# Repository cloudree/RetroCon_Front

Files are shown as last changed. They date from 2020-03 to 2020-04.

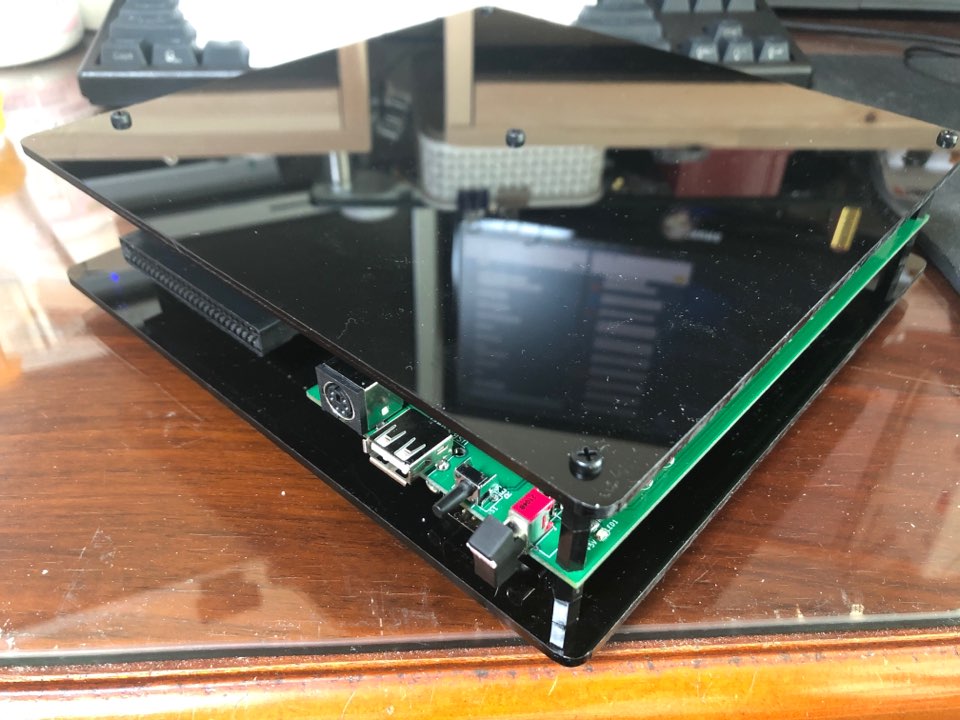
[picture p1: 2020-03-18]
Pictures/1_AcrylCased.JPG

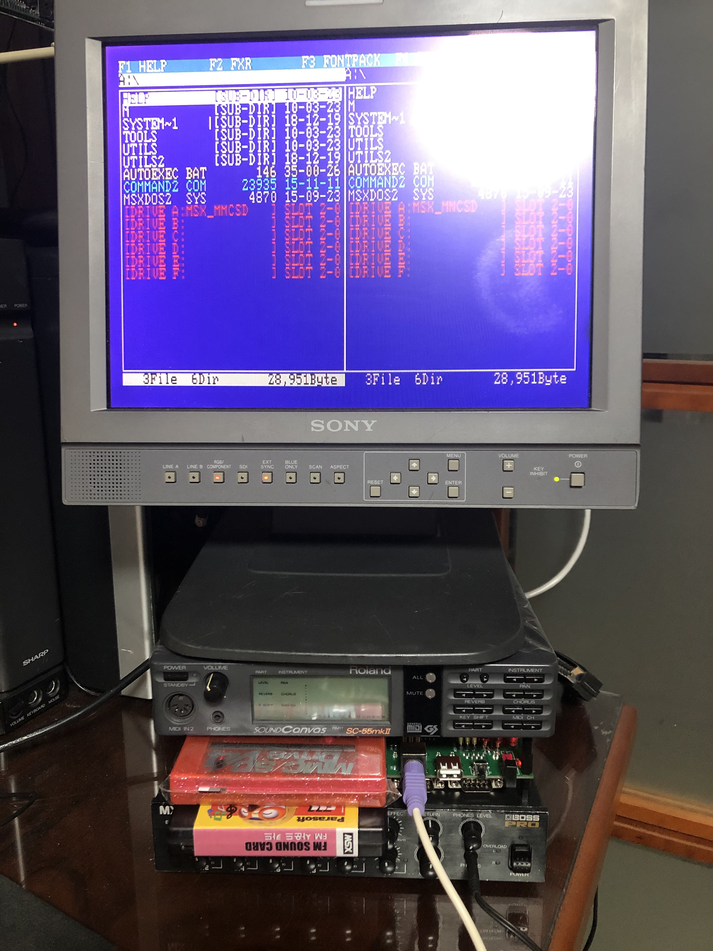
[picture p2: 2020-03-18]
Pictures/2_Between_MIDI_Devices.JPG

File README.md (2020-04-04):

# RetroCon_Front
Front Pack version of RetroCon (MSX2 compatible, VDP is V9958)
* Retrocon is MSX2+ compatible machine made by KevinCho ckevin@hanmail.net

/KiCad : schematics of Kicad

/CPLD : source for ALTERA EPM7128SLC84 CPLD, you must use Altera Quartus 13.0sp1 or below

/tinyFGPA : source for tinyFPGA board (PS/2 Keyboard interface)

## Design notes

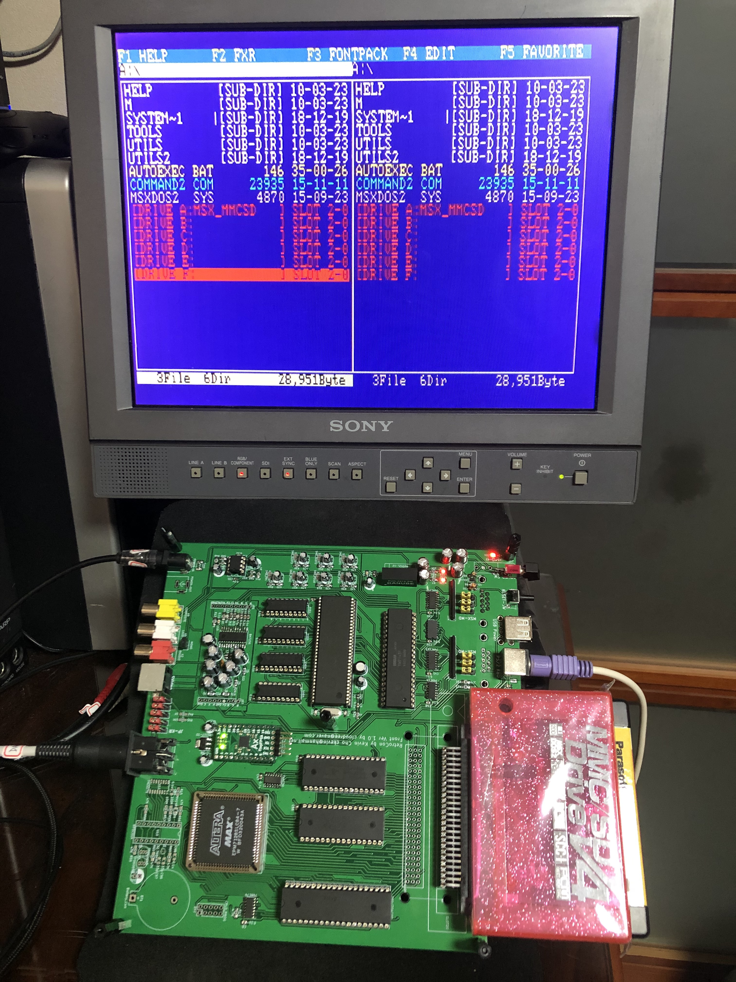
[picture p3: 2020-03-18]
Pictures/0_RetroCon.JPG

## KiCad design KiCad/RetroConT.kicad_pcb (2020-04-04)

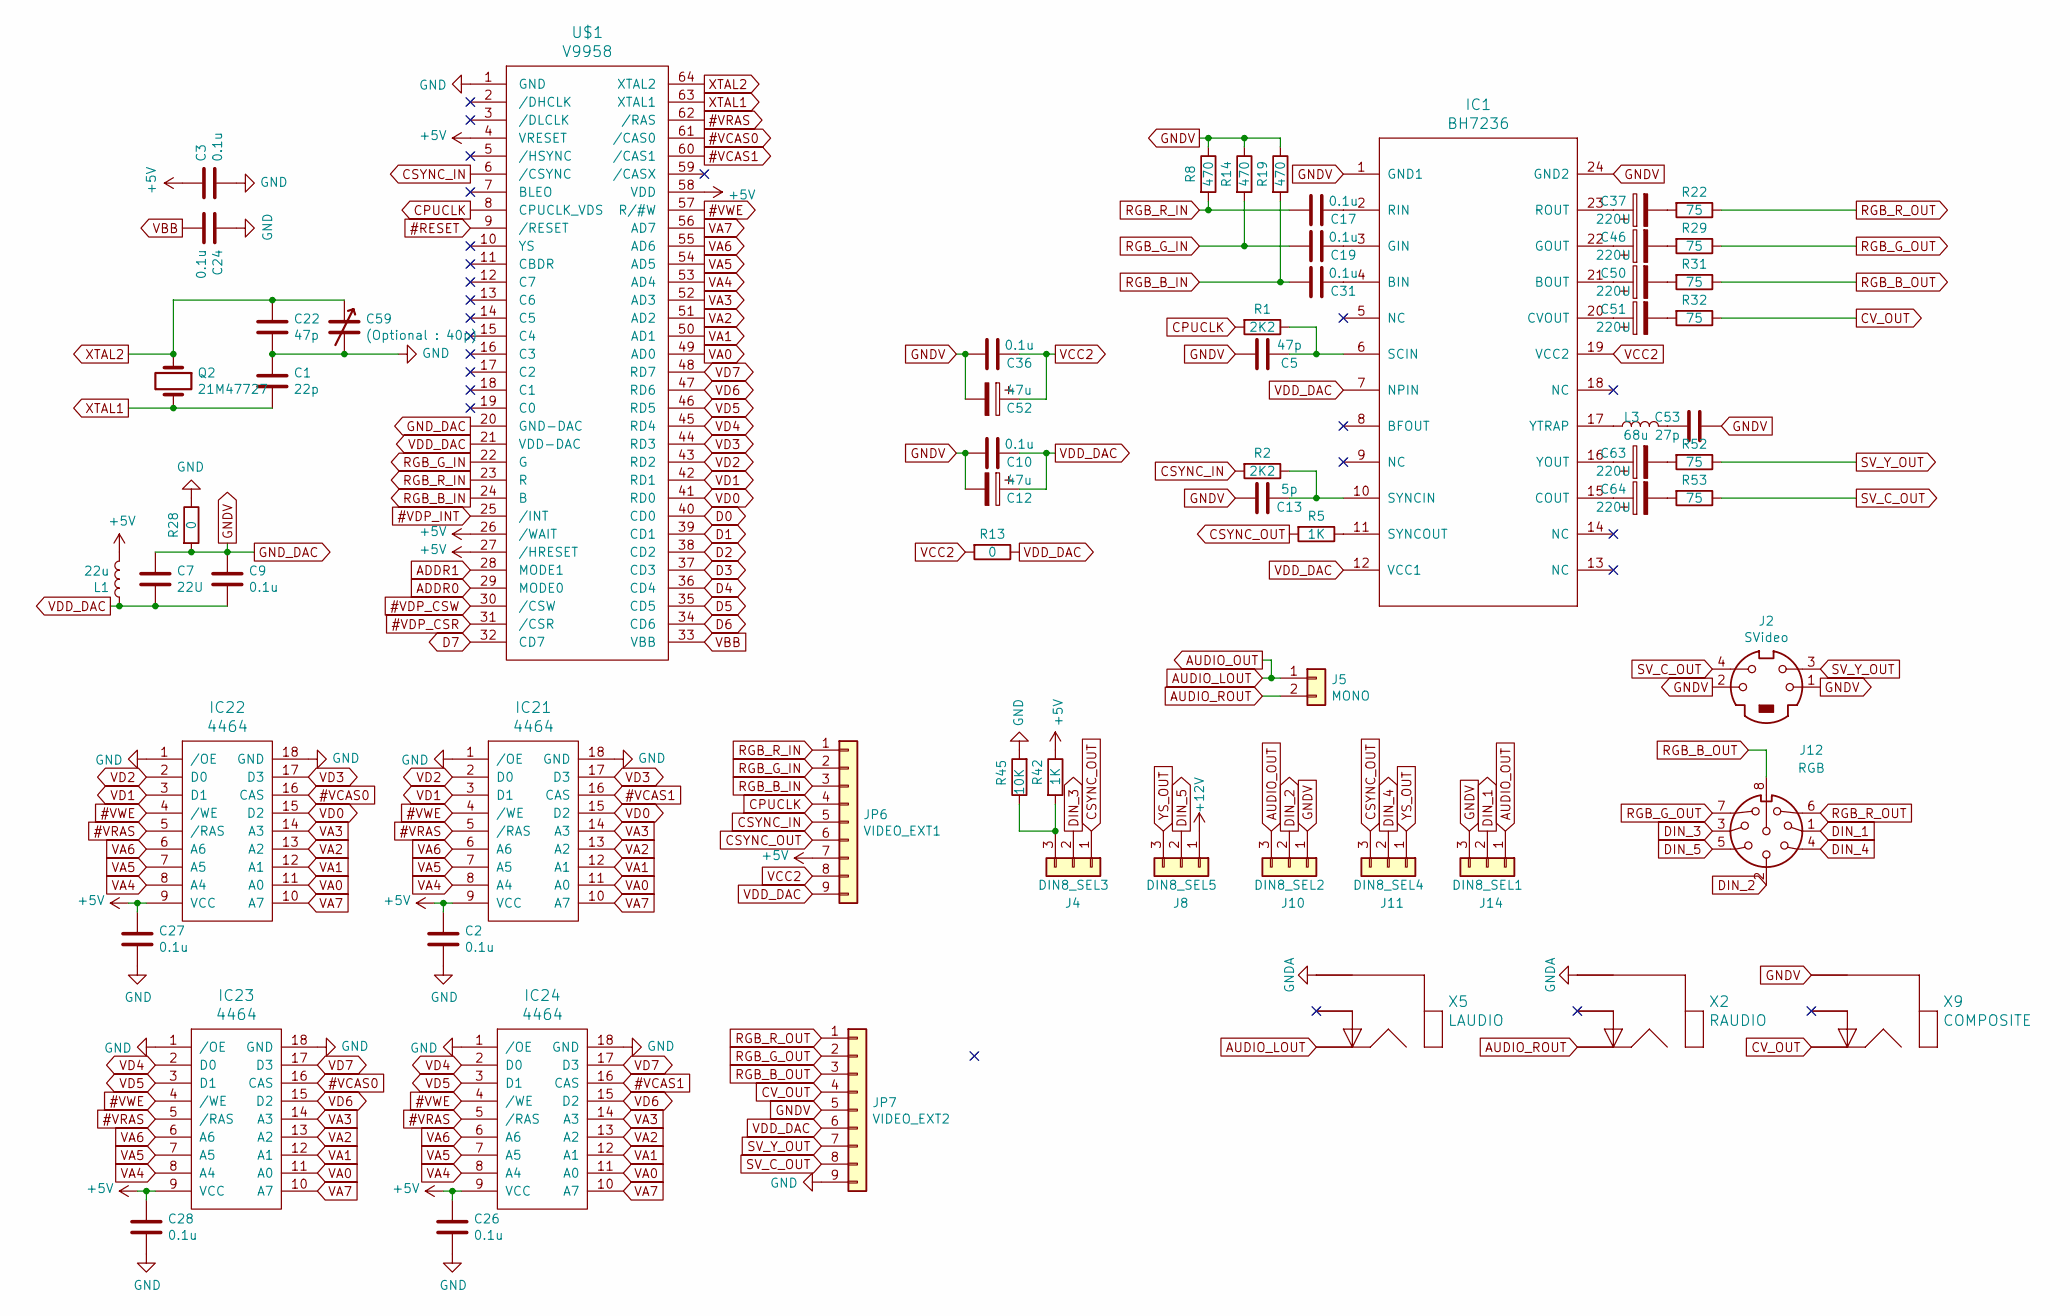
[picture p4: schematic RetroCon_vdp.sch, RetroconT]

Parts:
C1: 22p; C_0805_2012Metric_Pad1.15x1.40mm_HandSolder
C2, C3, C9, C10, C17, C19, C24, C26, C27, C28, C31, C36: 0.1u; C_0805_2012Metric_Pad1.15x1.40mm_HandSolder
C5, C22: 47p; C_0805_2012Metric_Pad1.15x1.40mm_HandSolder
C7: 22U; CP_Radial_D6.3mm_P2.50mm
C12, C52: 47u; CP_Radial_D6.3mm_P2.50mm
C13: 5p; C_0805_2012Metric_Pad1.15x1.40mm_HandSolder
C37, C46, C50, C51, C63, C64: 220U; CP_Radial_D6.3mm_P2.50mm
C53: 27p; C_0805_2012Metric_Pad1.15x1.40mm_HandSolder
C59: (Optional : 40p); C_Rect_L7.0mm_W6.5mm_P5.00mm
IC1: BH7236; SOP-24_7.5x15.4mm_P1.27mm
IC21, IC22, IC23, IC24: 4464; DIP-18_W7.62mm_Socket
J2: SVideo; Mini_din4
J4: DIN8_SEL3; PinHeader_1x03_P2.54mm_Vertical
J5: MONO; PinSocket_2x01_P2.54mm_Vertical
J8: DIN8_SEL5; PinHeader_1x03_P2.54mm_Vertical
J10: DIN8_SEL2; PinHeader_1x03_P2.54mm_Vertical
J11: DIN8_SEL4; PinHeader_1x03_P2.54mm_Vertical
J12: RGB; DIN-804_8P
J14: DIN8_SEL1; PinHeader_1x03_P2.54mm_Vertical
JP6: VIDEO_EXT1; PinHeader_1x09_P2.54mm_Vertical
JP7: VIDEO_EXT2; PinHeader_1x09_P2.54mm_Vertical
L1: 22u; L_0805_2012Metric_Pad1.15x1.40mm_HandSolder
L3: 68u; L_0805_2012Metric_Pad1.15x1.40mm_HandSolder
Q2: 21M47727; Crystal_HC49-U_Vertical
R1, R2: 2K2; R_0805_HandSoldering
R5, R42: 1K; R_0805_HandSoldering
R8, R14, R19: 470; R_0805_HandSoldering
R13, R28: 0; R_0805_HandSoldering
R22, R29, R31, R32, R52, R53: 75; R_0805_HandSoldering
R45: 10K; R_0805_HandSoldering
U$1: V9958; SDIP-64
X2: RAUDIO; RCA_102
X5: LAUDIO; RCA_102
X9: COMPOSITE; RCA_102

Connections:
#ExRESET: U$1.9 (/RESET); also elsewhere on the board
#VCAS0: IC22.16 (CAS), IC23.16 (CAS), U$1.61 (/CAS0)
#VCAS1: IC21.16 (CAS), IC24.16 (CAS), U$1.60 (/CAS1)
#VDP_CSR: U$1.31 (/CSR); also elsewhere on the board
#VDP_CSW: U$1.30 (/CSW); also elsewhere on the board
#VDP_INT: U$1.25 (/INT); also elsewhere on the board
#VRAS: IC21.5 (/RAS), IC22.5 (/RAS), IC23.5 (/RAS), IC24.5 (/RAS), U$1.62 (/RAS)
#VWE: IC21.4 (/WE), IC22.4 (/WE), IC23.4 (/WE), IC24.4 (/WE), U$1.57 (R/#W)
+5V: C2.1, C3.1, C26.1, C27.1, C28.1, IC21.9 (VCC), IC22.9 (VCC), IC23.9 (VCC), IC24.9 (VCC), JP6.7, L1.2, R42.1, U$1.4 (VRESET), U$1.26 (/WAIT), U$1.27 (/HRESET), U$1.58 (VDD); also elsewhere on the board
+12V: J8.1; also elsewhere on the board
ADDR0: U$1.29 (MODE0); also elsewhere on the board
ADDR1: U$1.28 (MODE1); also elsewhere on the board
AUDIO_LOUT: J5.1, J10.3, J14.1, X5.2; also elsewhere on the board
AUDIO_ROUT: J5.2, X2.2; also elsewhere on the board
CPUCLK: JP6.4, R1.2, U$1.8 (CPUCLK_VDS); also elsewhere on the board
CSYNC_IN: JP6.5, R2.2, U$1.6 (/CSYNC)
CSYNC_OUT: J4.1, J11.3, JP6.6, R5.2
CV_OUT: JP7.4, R32.1, X9.2
D0: U$1.40 (CD0); also elsewhere on the board
D1: U$1.39 (CD1); also elsewhere on the board
D2: U$1.38 (CD2); also elsewhere on the board
D3: U$1.37 (CD3); also elsewhere on the board
D4: U$1.36 (CD4); also elsewhere on the board
D5: U$1.35 (CD5); also elsewhere on the board
D6: U$1.34 (CD6); also elsewhere on the board
D7: U$1.32 (CD7); also elsewhere on the board
DIN_1: J12.1, J14.2
DIN_2: J10.2, J12.2
DIN_3: J4.2, J12.3
DIN_4: J11.2, J12.4
DIN_5: J8.2, J12.5
GND: C1.1, C2.2, C3.2, C22.2, C24.1, C26.2, C27.2, C28.2, C59.2, IC21.1 (/OE), IC21.18 (GND), IC22.1 (/OE), IC22.18 (GND), IC23.1 (/OE), IC23.18 (GND), IC24.1 (/OE), IC24.18 (GND), JP7.9, R28.1, R45.2, U$1.1 (GND); also elsewhere on the board
GNDA: X2.1, X5.1; also elsewhere on the board
GNDV: C5.2, C7.2, C9.2, C10.2, C12.2, C13.2, C36.2, C52.2, C53.2, IC1.1 (GND1), IC1.24 (GND2), J2.1, J2.2, J10.1, J14.3, JP7.5, R8.1, R14.1, R19.1, R28.2, U$1.20 (GND-DAC), X9.1
unnamed: C5.1, IC1.6 (SCIN), R1.1
unnamed: C13.1, IC1.10 (SYNCIN), R2.1
unnamed: C17.1, IC1.2 (RIN)
unnamed: C19.1, IC1.3 (GIN)
unnamed: C31.1, IC1.4 (BIN)
unnamed: C37.1, IC1.23 (ROUT)
unnamed: C37.2, R22.2
unnamed: C46.1, IC1.22 (GOUT)
unnamed: C46.2, R29.2
unnamed: C50.1, IC1.21 (BOUT)
unnamed: C50.2, R31.2
unnamed: C51.1, IC1.20 (CVOUT)
unnamed: C51.2, R32.2
unnamed: C53.1, L3.2
unnamed: C63.1, IC1.16 (YOUT)
unnamed: C63.2, R52.2
unnamed: C64.1, IC1.15 (COUT)
unnamed: C64.2, R53.2
unnamed: IC1.11 (SYNCOUT), R5.1
unnamed: IC1.17 (YTRAP), L3.1
unnamed: J4.3, R42.2, R45.1
RGB_B_IN: C31.2, JP6.3, R19.2, U$1.24 (B)
RGB_B_OUT: J12.8, JP7.3, R31.1
RGB_G_IN: C19.2, JP6.2, R14.2, U$1.22 (G)
RGB_G_OUT: J12.7, JP7.2, R29.1
RGB_R_IN: C17.2, JP6.1, R8.2, U$1.23 (R)
RGB_R_OUT: J12.6, JP7.1, R22.1
SV_C_OUT: J2.4, JP7.8, R53.1
SV_Y_OUT: J2.3, JP7.7, R52.1
VA0: IC21.11 (A0), IC22.11 (A0), IC23.11 (A0), IC24.11 (A0), U$1.49 (AD0)
VA1: IC21.12 (A1), IC22.12 (A1), IC23.12 (A1), IC24.12 (A1), U$1.50 (AD1)
VA2: IC21.13 (A2), IC22.13 (A2), IC23.13 (A2), IC24.13 (A2), U$1.51 (AD2)
VA3: IC21.14 (A3), IC22.14 (A3), IC23.14 (A3), IC24.14 (A3), U$1.52 (AD3)
VA4: IC21.8 (A4), IC22.8 (A4), IC23.8 (A4), IC24.8 (A4), U$1.53 (AD4)
VA5: IC21.7 (A5), IC22.7 (A5), IC23.7 (A5), IC24.7 (A5), U$1.54 (AD5)
VA6: IC21.6 (A6), IC22.6 (A6), IC23.6 (A6), IC24.6 (A6), U$1.55 (AD6)
VA7: IC21.10 (A7), IC22.10 (A7), IC23.10 (A7), IC24.10 (A7), U$1.56 (AD7)
VBB: C24.2, U$1.33 (VBB)
VCC2: C36.1, C52.1, IC1.19 (VCC2), JP6.8, R13.2
VD0: IC21.15 (D2), IC22.15 (D2), U$1.41 (RD0)
VD1: IC21.3 (D1), IC22.3 (D1), U$1.42 (RD1)
VD2: IC21.2 (D0), IC22.2 (D0), U$1.43 (RD2)
VD3: IC21.17 (D3), IC22.17 (D3), U$1.44 (RD3)
VD4: IC23.2 (D0), IC24.2 (D0), U$1.45 (RD4)
VD5: IC23.3 (D1), IC24.3 (D1), U$1.46 (RD5)
VD6: IC23.15 (D2), IC24.15 (D2), U$1.47 (RD6)
VD7: IC23.17 (D3), IC24.17 (D3), U$1.48 (RD7)
VDD_DAC: C7.1, C9.1, C10.1, C12.1, IC1.7 (NPIN), IC1.12 (VCC1), JP6.9, JP7.6, L1.1, R13.1, U$1.21 (VDD-DAC)
XTAL1: C1.2, Q2.2, U$1.63 (XTAL1)
XTAL2: C22.1, C59.1, Q2.1, U$1.64 (XTAL2)
YS_OUT: J8.3, J11.1

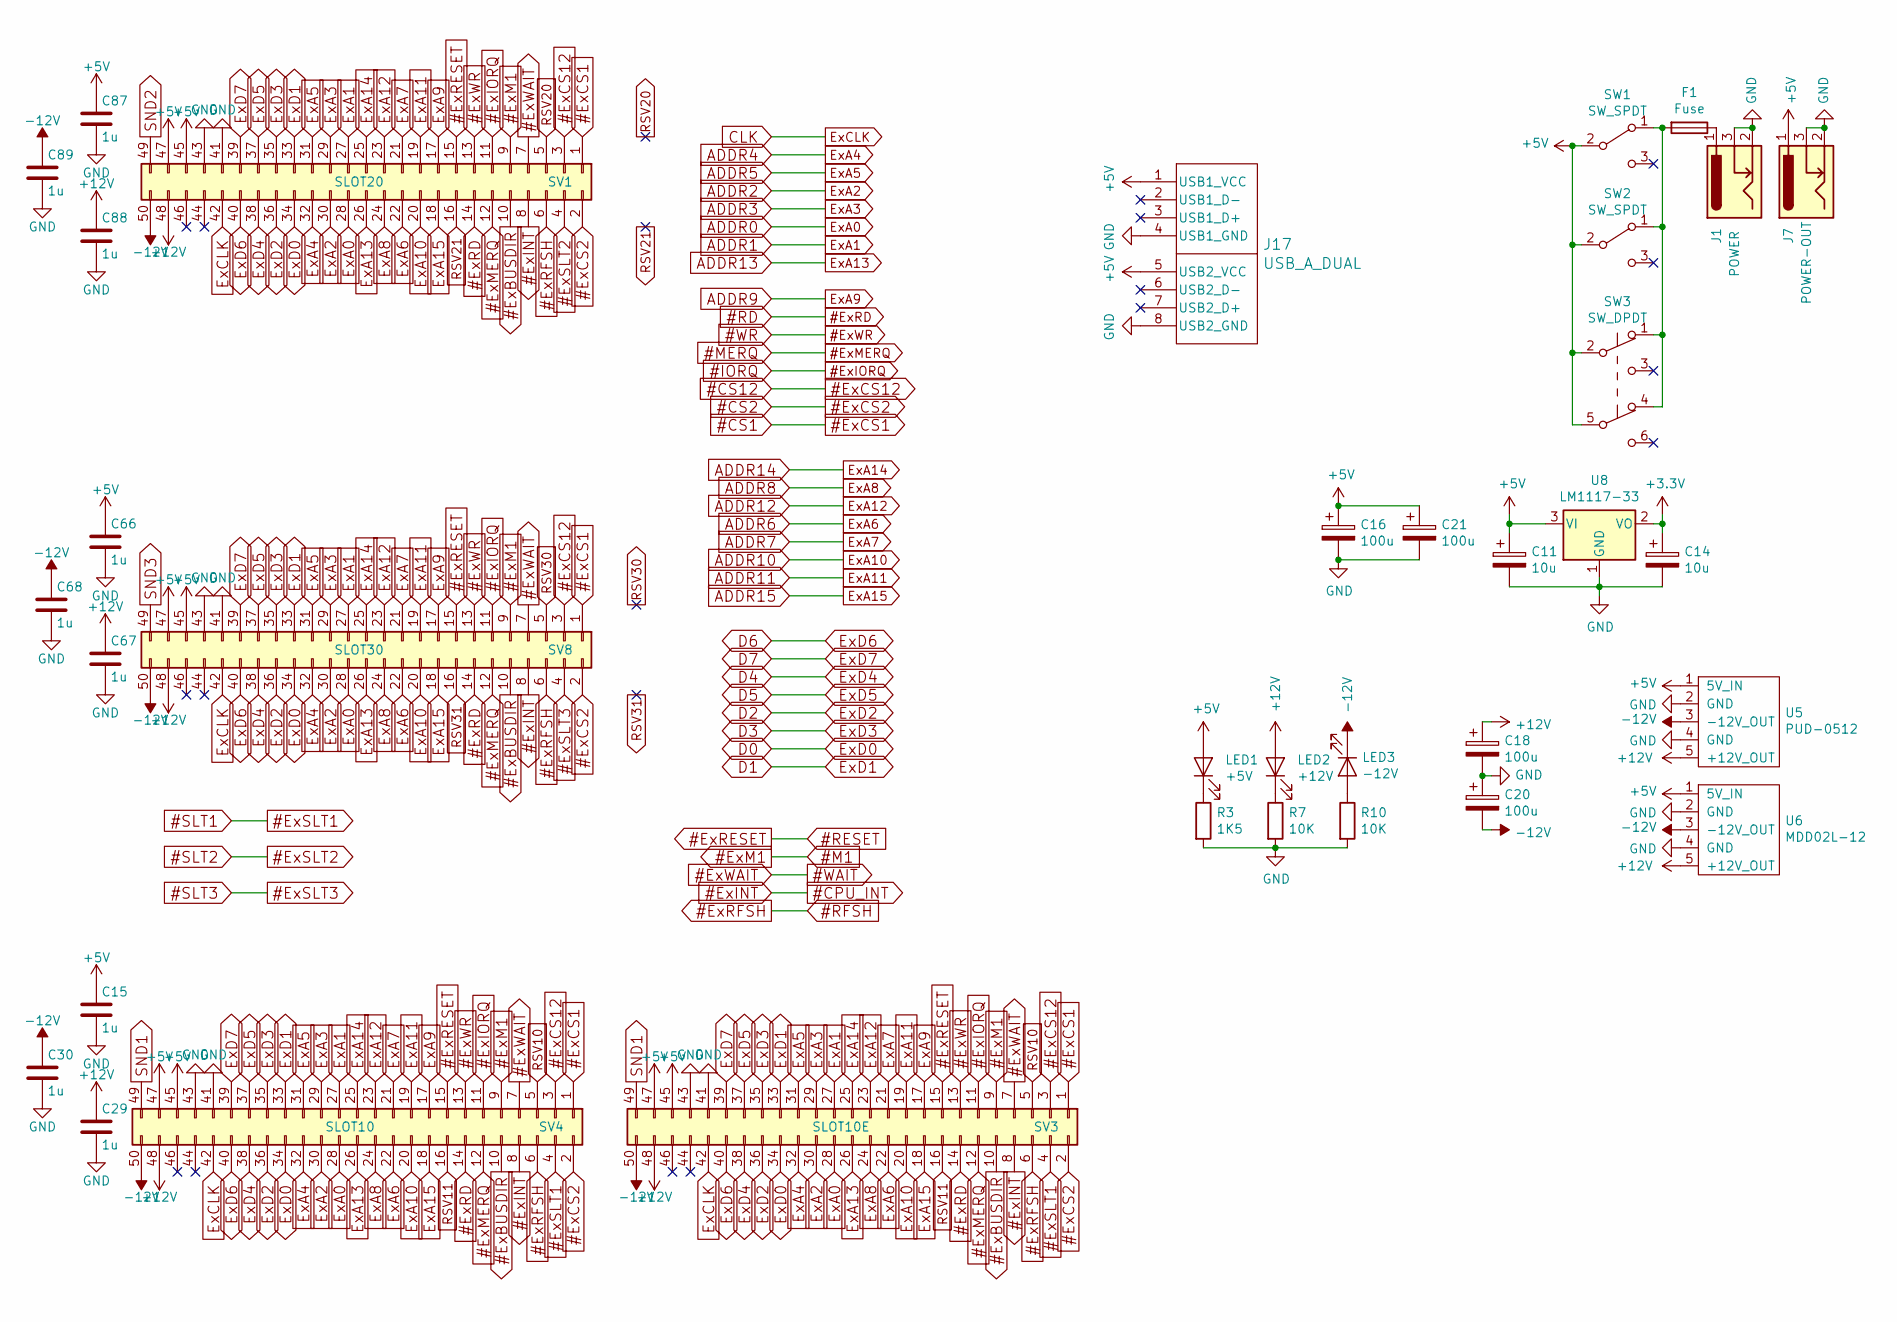
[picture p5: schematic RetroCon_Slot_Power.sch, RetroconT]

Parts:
C11, C14: 10u; CP_Radial_D6.3mm_P2.50mm
C15, C29, C30, C66, C67, C68, C87, C88, C89: 1u; C_0805_2012Metric_Pad1.15x1.40mm_HandSolder
C16, C18, C20, C21: 100u; CP_Radial_D6.3mm_P2.50mm
F1: Fuse; Fuse_1812_4532Metric_Pad1.30x3.40mm_HandSolder
J1: POWER; PO-PowerJack
J7: POWER-OUT; PO-PowerJack
J17: USB_A_DUAL
LED1: +5V; LED_0805_2012Metric
LED2: +12V; LED_0805_2012Metric
LED3: -12V; LED_0805_2012Metric
R3: 1K5; R_0805_HandSoldering
R7, R10: 10K; R_0805_HandSoldering
SV1: SLOT20; MSX_Edge_50_Slot
SV3: SLOT10E; MSX_Edge_50_Slot_Conencter
SV4: SLOT10; MSX_Edge_50_Slot
SV8: SLOT30; MSX_Edge_50_Slot_Universal
SW1: SW_SPDT; Switch-Toggle-Mini
SW2: SW_SPDT; MTS-102_Vertical_PCB
SW3: SW_DPDT; SW_DPDT_PS-22E05
U5: PUD-0512
U6: MDD02L-12
U8: LM1117-33; SOT-223-3_TabPin2

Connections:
#CPU_INT: SV1.8, SV3.8, SV4.8, SV8.8; also elsewhere on the board
#CS1: SV1.1, SV3.1, SV4.1, SV8.1; also elsewhere on the board
#CS2: SV1.2, SV3.2, SV4.2, SV8.2; also elsewhere on the board
#CS12: SV1.3, SV3.3, SV4.3, SV8.3; also elsewhere on the board
#ExBUSDIR: SV1.10, SV3.10, SV4.10, SV8.10
#ExIORQ: SV1.11, SV3.11, SV4.11, SV8.11; also elsewhere on the board
#ExM1: SV1.9, SV3.9, SV4.9, SV8.9; also elsewhere on the board
#ExMERQ: SV1.12, SV3.12, SV4.12, SV8.12; also elsewhere on the board
#ExRD: SV1.14, SV3.14, SV4.14, SV8.14; also elsewhere on the board
#ExRESET: SV1.15, SV3.15, SV4.15, SV8.15; also elsewhere on the board
#ExRFSH: SV1.6, SV3.6, SV4.6, SV8.6; also elsewhere on the board
#ExSLT1: SV3.4, SV4.4; also elsewhere on the board
#ExSLT2: SV1.4; also elsewhere on the board
#ExSLT3: SV8.4; also elsewhere on the board
#ExWAIT: SV1.7, SV3.7, SV4.7, SV8.7; also elsewhere on the board
#ExWR: SV1.13, SV3.13, SV4.13, SV8.13; also elsewhere on the board
+3V3: C14.1, U8.2 (VO); also elsewhere on the board
+5V: C11.1, C15.1, C16.1, C21.1, C66.1, C87.1, J7.1, J17.1 (USB1_VCC), J17.5 (USB2_VCC), LED1.2 (A), SV1.45, SV1.47, SV3.45, SV3.47, SV4.45, SV4.47, SV8.45, SV8.47, SW1.2 (B), SW2.2 (B), SW3.2 (B), SW3.5 (B), U5.1 (5V_IN), U6.1 (5V_IN), U8.3 (VI); also elsewhere on the board
+12V: C18.1, C29.1, C67.1, C88.1, LED2.2 (A), SV1.48, SV3.48, SV4.48, SV8.48, U5.5 (+12V_OUT), U6.5 (+12V_OUT); also elsewhere on the board
-12V: C20.2, C30.1, C68.1, C89.1, LED3.1 (K), SV1.50, SV3.50, SV4.50, SV8.50, U5.3 (-12V_OUT), U6.3 (-12V_OUT); also elsewhere on the board
ADDR0: SV1.28, SV3.28, SV4.28, SV8.28; also elsewhere on the board
ADDR1: SV1.27, SV3.27, SV4.27, SV8.27; also elsewhere on the board
ADDR2: SV1.30, SV3.30, SV4.30, SV8.30; also elsewhere on the board
ADDR3: SV1.29, SV3.29, SV4.29, SV8.29; also elsewhere on the board
ADDR4: SV1.32, SV3.32, SV4.32, SV8.32; also elsewhere on the board
ADDR5: SV1.31, SV3.31, SV4.31, SV8.31; also elsewhere on the board
ADDR6: SV1.22, SV3.22, SV4.22, SV8.22; also elsewhere on the board
ADDR7: SV1.21, SV3.21, SV4.21, SV8.21; also elsewhere on the board
ADDR8: SV1.24, SV3.24, SV4.24, SV8.24; also elsewhere on the board
ADDR9: SV1.17, SV3.17, SV4.17, SV8.17; also elsewhere on the board
ADDR10: SV1.20, SV3.20, SV4.20, SV8.20; also elsewhere on the board
ADDR11: SV1.19, SV3.19, SV4.19, SV8.19; also elsewhere on the board
ADDR12: SV1.23, SV3.23, SV4.23, SV8.23; also elsewhere on the board
ADDR13: SV1.26, SV3.26, SV4.26, SV8.26; also elsewhere on the board
ADDR14: SV1.25, SV3.25, SV4.25, SV8.25; also elsewhere on the board
ADDR15: SV1.18, SV3.18, SV4.18, SV8.18; also elsewhere on the board
CLK: SV1.42, SV3.42, SV4.42, SV8.42; also elsewhere on the board
D0: SV1.34, SV3.34, SV4.34, SV8.34; also elsewhere on the board
D1: SV1.33, SV3.33, SV4.33, SV8.33; also elsewhere on the board
D2: SV1.36, SV3.36, SV4.36, SV8.36; also elsewhere on the board
D3: SV1.35, SV3.35, SV4.35, SV8.35; also elsewhere on the board
D4: SV1.38, SV3.38, SV4.38, SV8.38; also elsewhere on the board
D5: SV1.37, SV3.37, SV4.37, SV8.37; also elsewhere on the board
D6: SV1.40, SV3.40, SV4.40, SV8.40; also elsewhere on the board
D7: SV1.39, SV3.39, SV4.39, SV8.39; also elsewhere on the board
GND: C11.2, C14.2, C15.2, C16.2, C18.2, C20.1, C21.2, C29.2, C30.2, C66.2, C67.2, C68.2, C87.2, C88.2, C89.2, J1.2, J1.3, J7.2, J7.3, J17.4 (USB1_GND), J17.8 (USB2_GND), R3.2, R7.2, R10.2, SV1.41, SV1.43, SV3.41, SV3.43, SV4.41, SV4.43, SV8.41, SV8.43, U5.2 (GND), U5.4 (GND), U6.2 (GND), U6.4 (GND), U8.1 (GND); also elsewhere on the board
unnamed: F1.1, J1.1
unnamed: F1.2, SW1.1 (A), SW2.1 (A), SW3.1 (A), SW3.4 (A)
unnamed: LED1.1 (K), R3.1
unnamed: LED2.1 (K), R7.1
unnamed: LED3.2 (A), R10.1
RSV10: SV3.5, SV4.5
RSV11: SV3.16, SV4.16
RSV20: SV1.5
RSV21: SV1.16
RSV30: SV8.5
RSV31: SV8.16
SND1: SV3.49, SV4.49; also elsewhere on the board
SND2: SV1.49; also elsewhere on the board
SND3: SV8.49; also elsewhere on the board

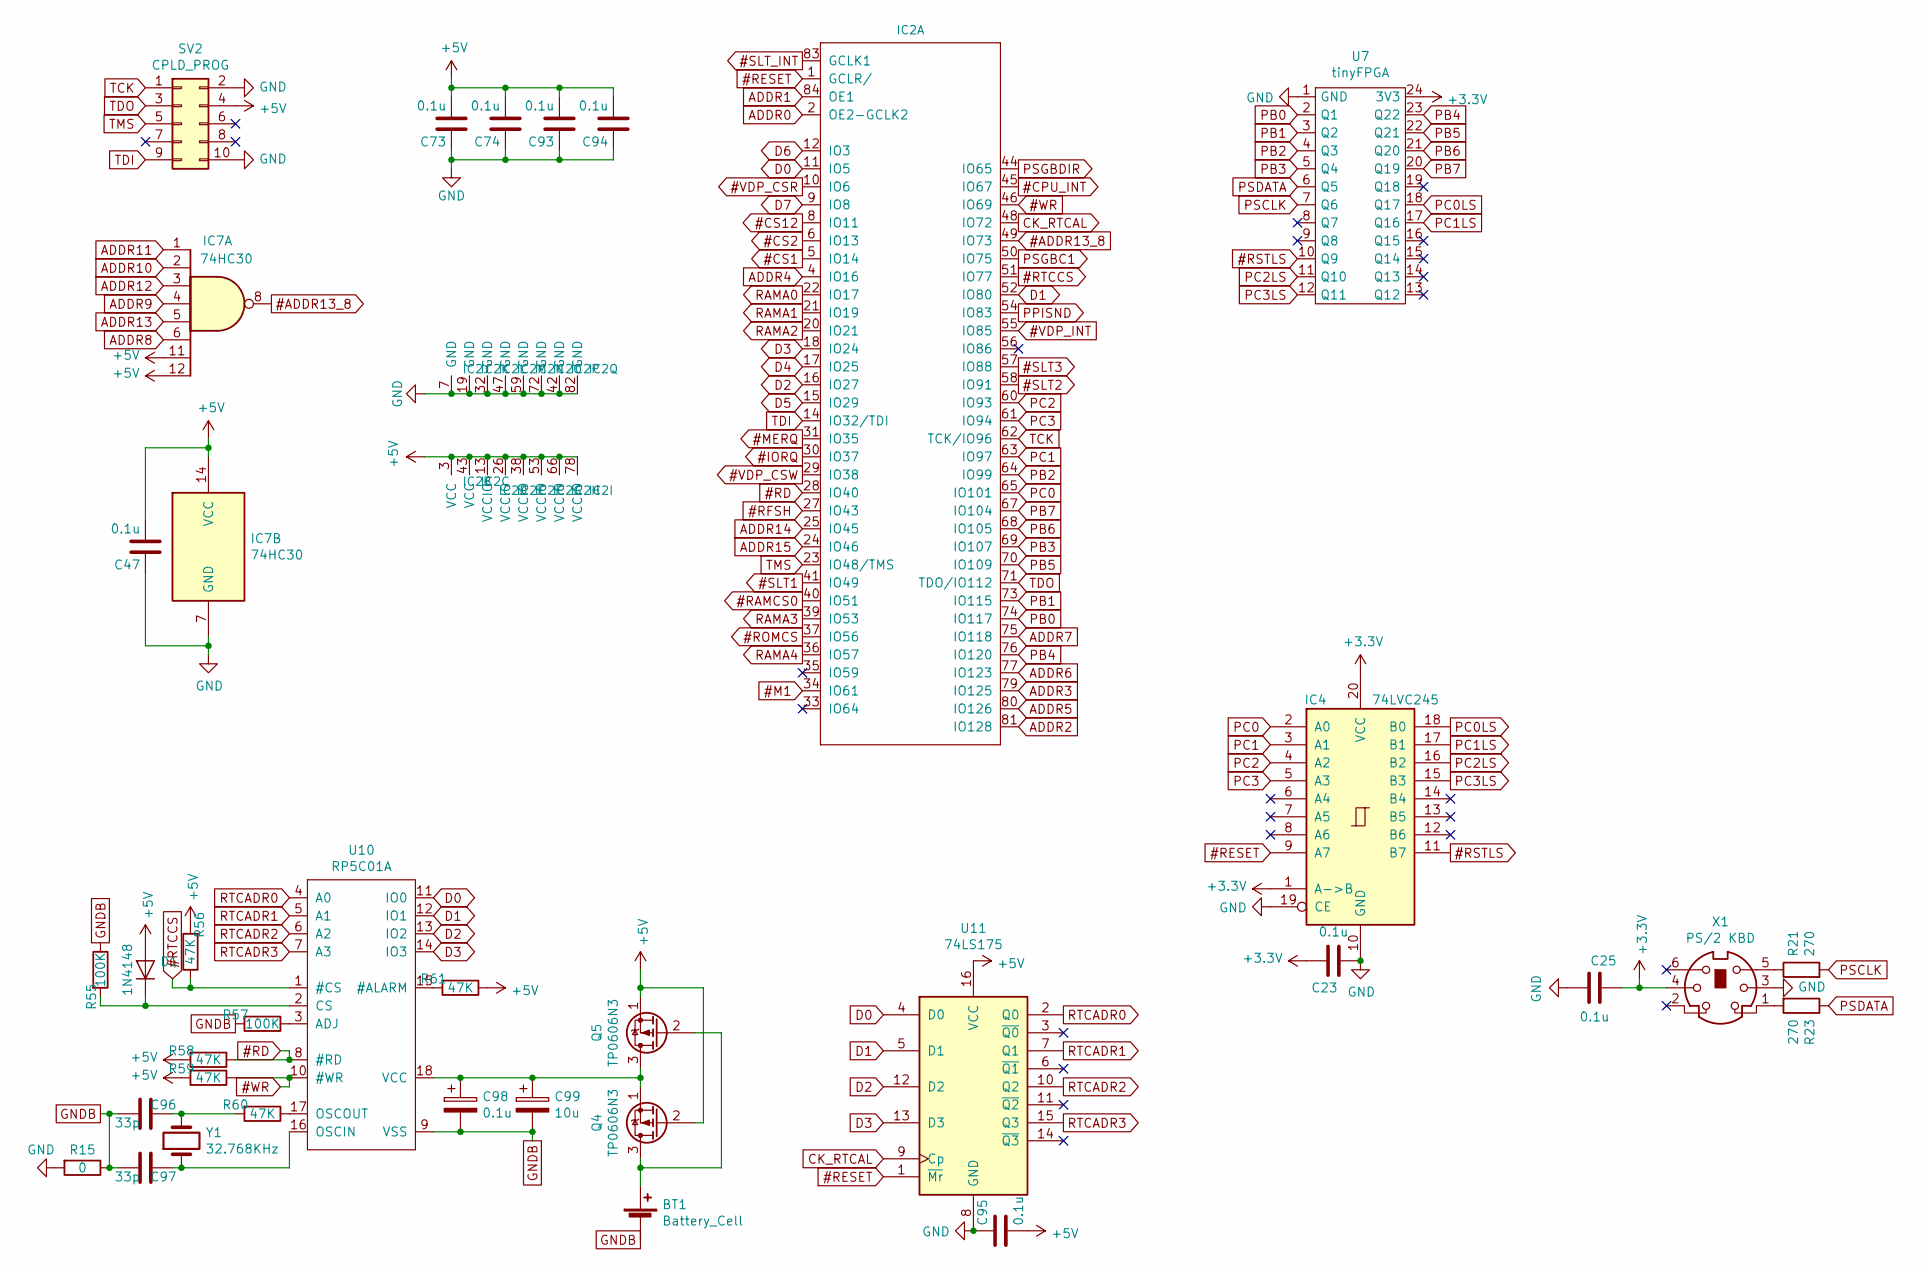
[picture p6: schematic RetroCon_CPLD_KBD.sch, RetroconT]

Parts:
BT1: Battery_Cell; BatteryHolder_Keystone_104_1x23mm
C23, C25, C47, C73, C74, C93, C94, C95, C98: 0.1u; C_0805_2012Metric_Pad1.15x1.40mm_HandSolder
C96, C97: 33p; C_0805_2012Metric_Pad1.15x1.40mm_HandSolder
C99: 10u; CP_Radial_D6.3mm_P2.50mm
D1: 1N4148; D_0805_2012Metric_Pad1.15x1.40mm_HandSolder
IC2: EPM7128-J84SOC-RetroCon-eagle-import; PLCC-84_THT-Socket
IC4: 74LVC245; DIP-20_W7.62mm_Socket
IC7: 74HC30; SOIC-14_3.9x8.7mm_P1.27mm
Q4, Q5: TP0606N3; TO-92_Inline
R15: 0; R_0805_HandSoldering
R21, R23: 270; R_0805_HandSoldering
R55, R57: 100K; R_0805_HandSoldering
R56, R58, R59, R60, R61: 47K; R_0805_HandSoldering
SV2: CPLD_PROG; PinHeader_2x05_P2.54mm_Vertical
U7: tinyFPGA; DIP-24_W15.24mm
U10: RP5C01A; DIP-18_W7.62mm_Socket
U11: 74LS175; SOIC-16_3.9x9.9mm_P1.27mm
X1: PS/2 KBD; Mini_din6
Y1: 32.768KHz; Crystal_DS26_D2.0mm_L6.0mm_Vertical

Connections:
#ADDR13_8: IC2.49 (IO73), IC7.8
#CPU_INT: IC2.45 (IO67); also elsewhere on the board
#CS1: IC2.5 (IO14); also elsewhere on the board
#CS2: IC2.6 (IO13); also elsewhere on the board
#CS12: IC2.8 (IO11); also elsewhere on the board
#ExIORQ: IC2.30 (IO37); also elsewhere on the board
#ExM1: IC2.34 (IO61); also elsewhere on the board
#ExMERQ: IC2.31 (IO35); also elsewhere on the board
#ExRD: IC2.28 (IO40), R58.1, U10.8 (#RD); also elsewhere on the board
#ExRESET: IC2.1 (GCLR/), IC4.9 (A7), U11.1 (~Mr); also elsewhere on the board
#ExRFSH: IC2.27 (IO43); also elsewhere on the board
#ExSLT1: IC2.41 (IO49); also elsewhere on the board
#ExSLT2: IC2.58 (IO91); also elsewhere on the board
#ExSLT3: IC2.57 (IO88); also elsewhere on the board
#ExWR: IC2.46 (IO69), R59.1, U10.10 (#WR); also elsewhere on the board
#RAMCS0: IC2.40 (IO51); also elsewhere on the board
#ROMCS: IC2.37 (IO56); also elsewhere on the board
#RSTLS: IC4.11 (B7), U7.10 (Q9)
#RTCCS: IC2.51 (IO77), R56.1, U10.1 (#CS)
#SLT_INT: IC2.83 (GCLK1); also elsewhere on the board
#VDP_CSR: IC2.10 (IO6); also elsewhere on the board
#VDP_CSW: IC2.29 (IO38); also elsewhere on the board
#VDP_INT: IC2.55 (IO85); also elsewhere on the board
+3V3: C23.2, C25.2, IC4.1 (A->B), IC4.20 (VCC), U7.24 (3V3), X1.4; also elsewhere on the board
+5V: C47.2, C73.2, C74.2, C93.2, C94.2, C95.2, D1.2 (A), IC2.3 (VCC), IC2.13 (VCCIO), IC2.26 (VCCIO), IC2.38 (VCCIO), IC2.43 (VCC), IC2.53 (VCCIO), IC2.66 (VCCIO), IC2.78 (VCCIO), IC7.11, IC7.12, IC7.14 (VCC), Q4.2 (G), Q5.1 (S), R56.2, R58.2, R59.2, R61.1, SV2.4, U11.16 (VCC); also elsewhere on the board
ADDR0: IC2.2 (OE2-GCLK2); also elsewhere on the board
ADDR1: IC2.84 (OE1); also elsewhere on the board
ADDR2: IC2.81 (IO128); also elsewhere on the board
ADDR3: IC2.79 (IO125); also elsewhere on the board
ADDR4: IC2.4 (IO16); also elsewhere on the board
ADDR5: IC2.80 (IO126); also elsewhere on the board
ADDR6: IC2.77 (IO123); also elsewhere on the board
ADDR7: IC2.75 (IO118); also elsewhere on the board
ADDR8: IC7.6; also elsewhere on the board
ADDR9: IC7.4; also elsewhere on the board
ADDR10: IC7.2; also elsewhere on the board
ADDR11: IC7.1; also elsewhere on the board
ADDR12: IC7.3; also elsewhere on the board
ADDR13: IC7.5; also elsewhere on the board
ADDR14: IC2.25 (IO45); also elsewhere on the board
ADDR15: IC2.24 (IO46); also elsewhere on the board
CK_RTCAL: IC2.48 (IO72), U11.9 (Cp)
D0: IC2.11 (IO5), U10.11 (IO0), U11.4 (D0); also elsewhere on the board
D1: IC2.52 (IO80), U10.12 (IO1), U11.5 (D1); also elsewhere on the board
D2: IC2.16 (IO27), U10.13 (IO2), U11.12 (D2); also elsewhere on the board
D3: IC2.18 (IO24), U10.14 (IO3), U11.13 (D3); also elsewhere on the board
D4: IC2.17 (IO25); also elsewhere on the board
D5: IC2.15 (IO29); also elsewhere on the board
D6: IC2.12 (IO3); also elsewhere on the board
D7: IC2.9 (IO8); also elsewhere on the board
GND: C23.1, C25.1, C47.1, C73.1, C74.1, C93.1, C94.1, C95.1, IC2.7 (GND), IC2.19 (GND), IC2.32 (GND), IC2.42 (GND), IC2.47 (GND), IC2.59 (GND), IC2.72 (GND), IC2.82 (GND), IC4.10 (GND), IC4.19 (CE), IC7.7 (GND), R15.2, SV2.2, SV2.10, U7.1 (GND), U11.8 (GND), X1.3; also elsewhere on the board
GNDB: BT1.2 (-), C96.1, C97.1, C98.2, C99.2, R15.1, R55.1, R57.2, U10.9 (VSS)
unnamed: BT1.1 (+), Q4.3 (D), Q5.2 (G)
unnamed: C96.2, R60.2, Y1.2
unnamed: C97.2, U10.16 (OSCIN), Y1.1
unnamed: C98.1, C99.1, Q4.1 (S), Q5.3 (D), U10.18 (VCC)
unnamed: D1.1 (K), R55.2, U10.2 (CS)
unnamed: R21.1, X1.5
unnamed: R23.2, X1.1
unnamed: R57.1, U10.3 (ADJ)
unnamed: R60.1, U10.17 (OSCOUT)
unnamed: R61.2, U10.15 (#ALARM)
PB0: IC2.74 (IO117), U7.2 (Q1)
PB1: IC2.73 (IO115), U7.3 (Q2)
PB2: IC2.64 (IO99), U7.4 (Q3)
PB3: IC2.69 (IO107), U7.5 (Q4)
PB4: IC2.76 (IO120), U7.23 (Q22)
PB5: IC2.70 (IO109), U7.22 (Q21)
PB6: IC2.68 (IO105), U7.21 (Q20)
PB7: IC2.67 (IO104), U7.20 (Q19)
PC0: IC2.65 (IO101), IC4.2 (A0)
PC0LS: IC4.18 (B0), U7.18 (Q17)
PC1: IC2.63 (IO97), IC4.3 (A1)
PC1LS: IC4.17 (B1), U7.17 (Q16)
PC2: IC2.60 (IO93), IC4.4 (A2)
PC2LS: IC4.16 (B2), U7.11 (Q10)
PC3: IC2.61 (IO94), IC4.5 (A3)
PC3LS: IC4.15 (B3), U7.12 (Q11)
PPISND: IC2.54 (IO83); also elsewhere on the board
PSCLK: R21.2, U7.7 (Q6)
PSDATA: R23.1, U7.6 (Q5)
PSGBC1: IC2.50 (IO75); also elsewhere on the board
PSGBDIR: IC2.44 (IO65); also elsewhere on the board
RAMA0: IC2.22 (IO17); also elsewhere on the board
RAMA1: IC2.21 (IO19); also elsewhere on the board
RAMA2: IC2.20 (IO21); also elsewhere on the board
RAMA3: IC2.39 (IO53); also elsewhere on the board
RAMA4: IC2.36 (IO57); also elsewhere on the board
RTCADR0: U10.4 (A0), U11.2 (Q0)
RTCADR1: U10.5 (A1), U11.7 (Q1)
RTCADR2: U10.6 (A2), U11.10 (Q2)
RTCADR3: U10.7 (A3), U11.15 (Q3)
TCK: IC2.62 (TCK/IO96), SV2.1
TDI: IC2.14 (IO32/TDI), SV2.9
TDO: IC2.71 (TDO/IO112), SV2.3
TMS: IC2.23 (IO48/TMS), SV2.5

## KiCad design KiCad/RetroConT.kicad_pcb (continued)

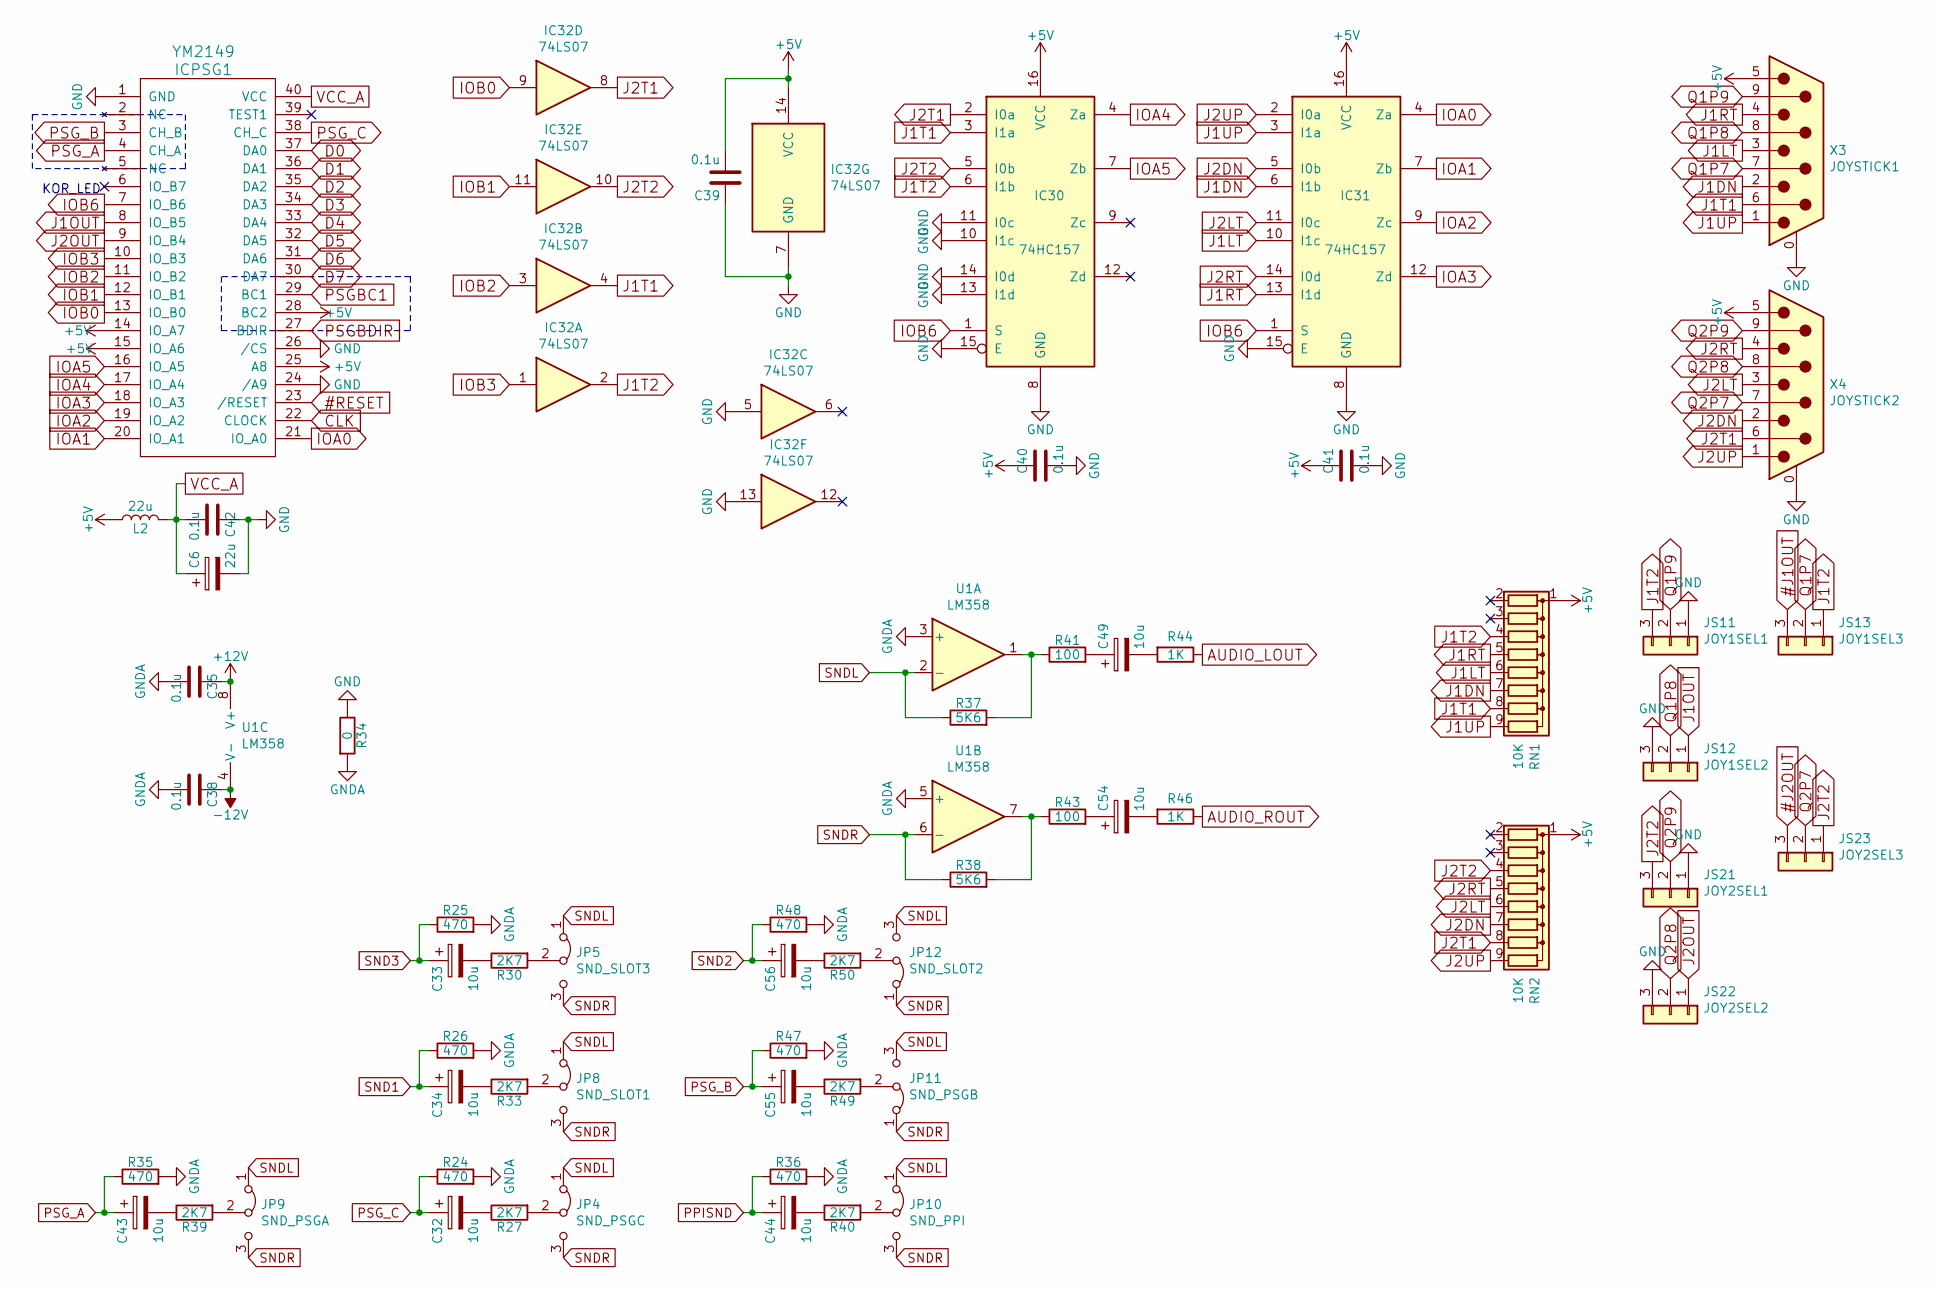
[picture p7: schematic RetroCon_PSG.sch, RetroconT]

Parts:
C6: 22u; CP_Radial_D6.3mm_P2.50mm
C32, C33, C34, C43, C44, C49, C54, C55, C56: 10u; CP_Radial_D6.3mm_P2.50mm
C35, C38, C39, C40, C41, C42: 0.1u; C_0805_2012Metric_Pad1.15x1.40mm_HandSolder
IC30, IC31: 74HC157; SOIC-16_3.9x9.9mm_P1.27mm
IC32: 74LS07; SOIC-14_3.9x8.7mm_P1.27mm
ICPSG1: YM2149; DIP-40_W15.24mm_Socket
JP4: SND_PSGC; SolderJumper-3_P1.3mm_Bridged12_RoundedPad1.0x1.5mm_NumberL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
JP5: SND_SLOT3; SolderJumper-3_P1.3mm_Bridged12_RoundedPad1.0x1.5mm_NumberL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
JP8: SND_SLOT1; SolderJumper-3_P1.3mm_Bridged12_RoundedPad1.0x1.5mm_NumberL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
JP9: SND_PSGA; SolderJumper-3_P1.3mm_Bridged12_RoundedPad1.0x1.5mm_NumberL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
JP10: SND_PPI; SolderJumper-3_P1.3mm_Bridged12_RoundedPad1.0x1.5mm_NumberL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
JP11: SND_PSGB; SolderJumper-3_P1.3mm_Bridged12_RoundedPad1.0x1.5mm_NumberL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
JP12: SND_SLOT2; SolderJumper-3_P1.3mm_Bridged12_RoundedPad1.0x1.5mm_NumberL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
JS11: JOY1SEL1; PinSocket_1x03_P2.54mm_Vertical
JS12: JOY1SEL2; PinSocket_1x03_P2.54mm_Vertical
JS13: JOY1SEL3; PinSocket_1x03_P2.54mm_Vertical
JS21: JOY2SEL1; PinSocket_1x03_P2.54mm_Vertical
JS22: JOY2SEL2; PinSocket_1x03_P2.54mm_Vertical
JS23: JOY2SEL3; PinSocket_1x03_P2.54mm_Vertical
L2: 22u; L_0805_2012Metric_Pad1.15x1.40mm_HandSolder
R24, R25, R26, R35, R36, R47, R48: 470; R_0805_HandSoldering
R27, R30, R33, R39, R40, R49, R50: 2K7; R_0805_HandSoldering
R34: 0; R_0805_HandSoldering
R37, R38: 5K6; R_0805_HandSoldering
R41, R43: 100; R_0805_HandSoldering
R44, R46: 1K; R_0805_HandSoldering
RN1, RN2: 10K; R_Array_SIP9
U1: LM358; DIP-8_W7.62mm_Socket
X3: JOYSTICK1; DSUB-9_Male_Horizontal_P2.77x2.84mm_EdgePinOffset4.94mm_Hou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
X4: JOYSTICK2; DSUB-9_Male_Horizontal_P2.77x2.84mm_EdgePinOffset4.94mm_Hou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

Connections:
#ExRESET: ICPSG1.23 (/RESET); also elsewhere on the board
#J1OUT: JS13.3; also elsewhere on the board
#J2OUT: JS23.3; also elsewhere on the board
+5V: C39.2, C40.1, C41.1, IC30.16 (VCC), IC31.16 (VCC), IC32.14 (VCC), ICPSG1.14 (IO_A7), ICPSG1.15 (IO_A6), ICPSG1.25 (A8), ICPSG1.28 (BC2), L2.1, RN1.1 (common), RN2.1 (common), X3.5, X4.5; also elsewhere on the board
+12V: C35.1, U1.8 (V+); also elsewhere on the board
-12V: C38.1, U1.4 (V-); also elsewhere on the board
AUDIO_LOUT: R44.1; also elsewhere on the board
AUDIO_ROUT: R46.1; also elsewhere on the board
CLK: ICPSG1.22 (CLOCK); also elsewhere on the board
D0: ICPSG1.37 (DA0); also elsewhere on the board
D1: ICPSG1.36 (DA1); also elsewhere on the board
D2: ICPSG1.35 (DA2); also elsewhere on the board
D3: ICPSG1.34 (DA3); also elsewhere on the board
D4: ICPSG1.33 (DA4); also elsewhere on the board
D5: ICPSG1.32 (DA5); also elsewhere on the board
D6: ICPSG1.31 (DA6); also elsewhere on the board
D7: ICPSG1.30 (DA7); also elsewhere on the board
GND: C6.2, C39.1, C40.2, C41.2, C42.1, IC30.8 (GND), IC30.10 (I1c), IC30.11 (I0c), IC30.13 (I1d), IC30.14 (I0d), IC30.15 (E), IC31.8 (GND), IC31.15 (E), IC32.5, IC32.7 (GND), IC32.13, ICPSG1.1 (GND), ICPSG1.24 (/A9), ICPSG1.26 (/CS), JS11.1, JS12.3, JS21.1, JS22.3, R34.1, X3.0 (PAD), X4.0 (PAD); also elsewhere on the board
GNDA: C35.2, C38.2, R24.2, R25.2, R26.2, R34.2, R35.2, R36.2, R47.2, R48.2, U1.3 (+), U1.5 (+); also elsewhere on the board
IOA0: IC31.4 (Za), ICPSG1.21 (IO_A0)
IOA1: IC31.7 (Zb), ICPSG1.20 (IO_A1)
IOA2: IC31.9 (Zc), ICPSG1.19 (IO_A2)
IOA3: IC31.12 (Zd), ICPSG1.18 (IO_A3)
IOA4: IC30.4 (Za), ICPSG1.17 (IO_A4)
IOA5: IC30.7 (Zb), ICPSG1.16 (IO_A5)
IOB0: IC32.9, ICPSG1.13 (IO_B0)
IOB1: IC32.11, ICPSG1.12 (IO_B1)
IOB2: IC32.3, ICPSG1.11 (IO_B2)
IOB3: IC32.1, ICPSG1.10 (IO_B3)
IOB6: IC30.1 (S), IC31.1 (S), ICPSG1.7 (IO_B6)
J1DN: IC31.6 (I1b), RN1.7 (R6), X3.2
J1LT: IC31.10 (I1c), RN1.6 (R5), X3.3
J1OUT: ICPSG1.8 (IO_B5), JS12.1; also elsewhere on the board
J1RT: IC31.13 (I1d), RN1.5 (R4), X3.4
J1T1: IC30.3 (I1a), IC32.4, RN1.8 (R7), X3.6
J1T2: IC30.6 (I1b), IC32.2, JS11.3, JS13.1, RN1.4 (R3)
J1UP: IC31.3 (I1a), RN1.9 (R8), X3.1
J2DN: IC31.5 (I0b), RN2.7 (R6), X4.2
J2LT: IC31.11 (I0c), RN2.6 (R5), X4.3
J2OUT: ICPSG1.9 (IO_B4), JS22.1; also elsewhere on the board
J2RT: IC31.14 (I0d), RN2.5 (R4), X4.4
J2T1: IC30.2 (I0a), IC32.8, RN2.8 (R7), X4.6
J2T2: IC30.5 (I0b), IC32.10, JS21.3, JS23.1, RN2.4 (R3)
J2UP: IC31.2 (I0a), RN2.9 (R8), X4.1
unnamed: C32.2, R27.1
unnamed: C33.2, R30.1
unnamed: C34.2, R33.1
unnamed: C43.2, R39.1
unnamed: C44.2, R40.1
unnamed: C49.1, R41.2
unnamed: C49.2, R44.2
unnamed: C54.1, R43.2
unnamed: C54.2, R46.2
unnamed: C55.2, R49.1
unnamed: C56.2, R50.1
unnamed: JP4.2 (C), R27.2
unnamed: JP5.2 (C), R30.2
unnamed: JP8.2 (C), R33.2
unnamed: JP9.2 (C), R39.2
unnamed: JP10.2 (C), R40.2
unnamed: JP11.2 (C), R49.2
unnamed: JP12.2 (C), R50.2
unnamed: R37.2, R41.1, U1.1
unnamed: R38.2, R43.1, U1.7
PPISND: C44.1, R36.1; also elsewhere on the board
PSGBC1: ICPSG1.29 (BC1); also elsewhere on the board
PSGBDIR: ICPSG1.27 (BDIR); also elsewhere on the board
PSG_A: C43.1, ICPSG1.4 (CH_A), R35.1
PSG_B: C55.1, ICPSG1.3 (CH_B), R47.1
PSG_C: C32.1, ICPSG1.38 (CH_C), R24.1
Q1P7: JS13.2, X3.7
Q1P8: JS12.2, X3.8
Q1P9: JS11.2, X3.9
Q2P7: JS23.2, X4.7
Q2P8: JS22.2, X4.8
Q2P9: JS21.2, X4.9
SND1: C34.1, R26.1; also elsewhere on the board
SND2: C56.1, R48.1; also elsewhere on the board
SND3: C33.1, R25.1; also elsewhere on the board
SNDL: JP4.1 (A), JP5.1 (A), JP8.1 (A), JP9.1 (A), JP10.1 (A), JP11.3 (B), JP12.3 (B), R37.1, U1.2 (-)
SNDR: JP4.3 (B), JP5.3 (B), JP8.3 (B), JP9.3 (B), JP10.3 (B), JP11.1 (A), JP12.1 (A), R38.1, U1.6 (-)
VCC_A: C6.1, C42.2, ICPSG1.40 (VCC), L2.2

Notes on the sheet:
KOR_LED

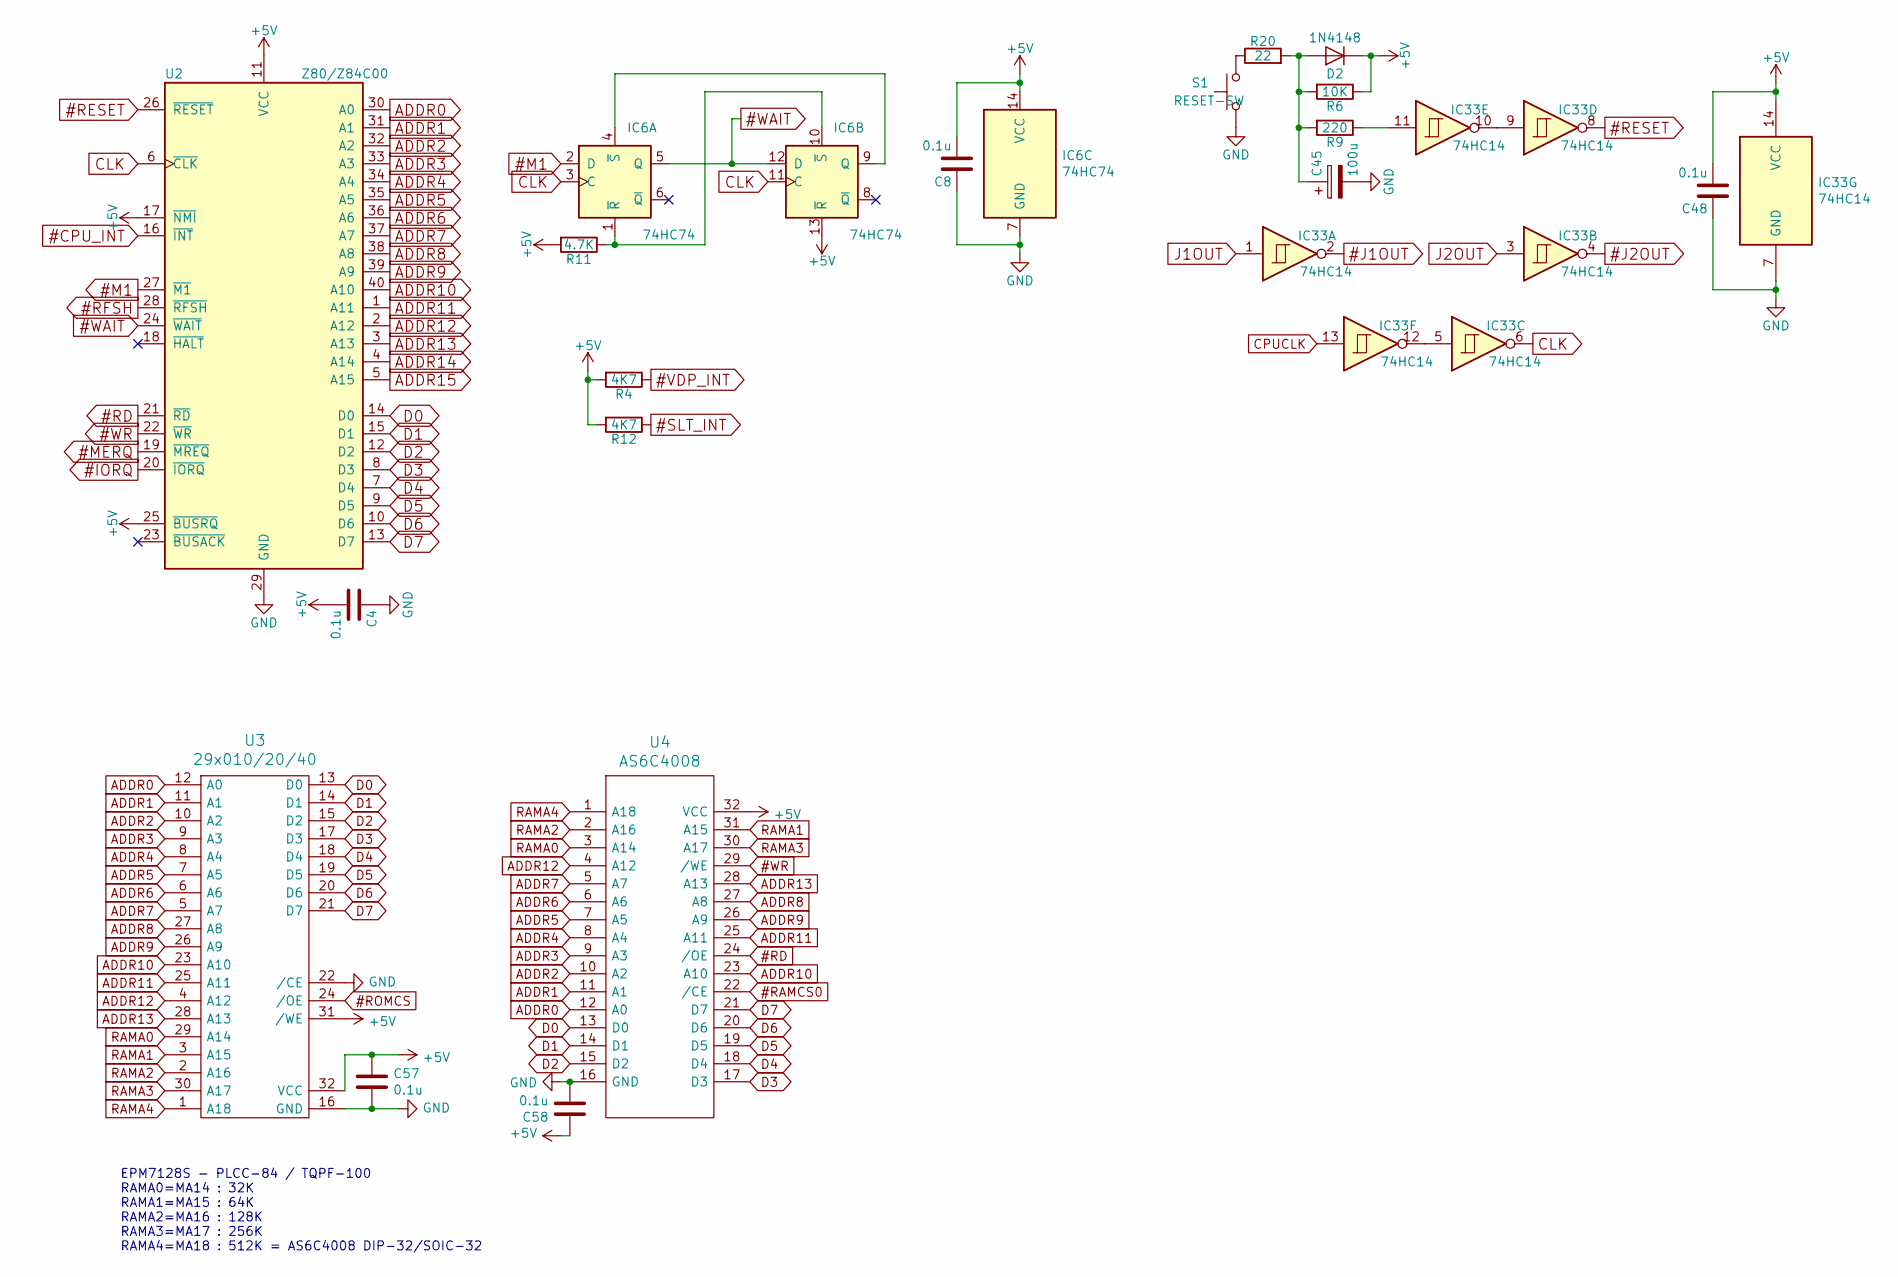
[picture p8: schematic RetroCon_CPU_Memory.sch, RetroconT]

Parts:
C4, C8, C48, C57, C58: 0.1u; C_0805_2012Metric_Pad1.15x1.40mm_HandSolder
C45: 100u; CP_Radial_D6.3mm_P2.50mm
D2: 1N4148; D_0805_2012Metric_Pad1.15x1.40mm_HandSolder
IC6: 74HC74; SOIC-14_3.9x8.7mm_P1.27mm
IC33: 74HC14; SOIC-14_3.9x8.7mm_P1.27mm
R4, R12: 4K7; R_0805_HandSoldering
R6: 10K; R_0805_HandSoldering
R9: 220; R_0805_HandSoldering
R11: 4.7K; R_0805_HandSoldering
R20: 22; R_0805_HandSoldering
S1: RESET-SW; Tact_Switch_Long_Angle
U2: Z80/Z84C00; DIP-40_W15.24mm_Socket
U3: 29x010/20/40; DIP-32_W15.24mm_Socket
U4: AS6C4008; DIP-32_W15.24mm_Socket

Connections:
#CPU_INT: U2.16 (~INT~); also elsewhere on the board
#ExIORQ: U2.20 (~IORQ~); also elsewhere on the board
#ExM1: IC6.2 (D), U2.27 (~M1~); also elsewhere on the board
#ExMERQ: U2.19 (~MREQ~); also elsewhere on the board
#ExRD: U2.21 (~RD~), U4.24 (/OE); also elsewhere on the board
#ExRESET: IC33.8, U2.26 (~RESET~); also elsewhere on the board
#ExRFSH: U2.28 (~RFSH~); also elsewhere on the board
#ExWAIT: IC6.5 (Q), IC6.12 (D), U2.24 (~WAIT~); also elsewhere on the board
#ExWR: U2.22 (~WR~), U4.29 (/WE); also elsewhere on the board
#J1OUT: IC33.2; also elsewhere on the board
#J2OUT: IC33.4; also elsewhere on the board
#RAMCS0: U4.22 (/CE); also elsewhere on the board
#ROMCS: U3.24 (/OE); also elsewhere on the board
#SLT_INT: R12.1; also elsewhere on the board
#VDP_INT: R4.1; also elsewhere on the board
+5V: C4.2, C8.2, C48.2, C57.1, C58.1, D2.1 (K), IC6.13 (~R), IC6.14 (VCC), IC33.14 (VCC), R4.2, R6.1, R11.2, R12.2, U2.11 (VCC), U2.17 (~NMI~), U2.25 (~BUSRQ~), U3.31 (/WE), U3.32 (VCC), U4.32 (VCC); also elsewhere on the board
ADDR0: U2.30 (A0), U3.12 (A0), U4.12 (A0); also elsewhere on the board
ADDR1: U2.31 (A1), U3.11 (A1), U4.11 (A1); also elsewhere on the board
ADDR2: U2.32 (A2), U3.10 (A2), U4.10 (A2); also elsewhere on the board
ADDR3: U2.33 (A3), U3.9 (A3), U4.9 (A3); also elsewhere on the board
ADDR4: U2.34 (A4), U3.8 (A4), U4.8 (A4); also elsewhere on the board
ADDR5: U2.35 (A5), U3.7 (A5), U4.7 (A5); also elsewhere on the board
ADDR6: U2.36 (A6), U3.6 (A6), U4.6 (A6); also elsewhere on the board
ADDR7: U2.37 (A7), U3.5 (A7), U4.5 (A7); also elsewhere on the board
ADDR8: U2.38 (A8), U3.27 (A8), U4.27 (A8); also elsewhere on the board
ADDR9: U2.39 (A9), U3.26 (A9), U4.26 (A9); also elsewhere on the board
ADDR10: U2.40 (A10), U3.23 (A10), U4.23 (A10); also elsewhere on the board
ADDR11: U2.1 (A11), U3.25 (A11), U4.25 (A11); also elsewhere on the board
ADDR12: U2.2 (A12), U3.4 (A12), U4.4 (A12); also elsewhere on the board
ADDR13: U2.3 (A13), U3.28 (A13), U4.28 (A13); also elsewhere on the board
ADDR14: U2.4 (A14); also elsewhere on the board
ADDR15: U2.5 (A15); also elsewhere on the board
CLK: IC6.3 (C), IC6.11 (C), IC33.6, U2.6 (~CLK~); also elsewhere on the board
CPUCLK: IC33.13; also elsewhere on the board
D0: U2.14 (D0), U3.13 (D0), U4.13 (D0); also elsewhere on the board
D1: U2.15 (D1), U3.14 (D1), U4.14 (D1); also elsewhere on the board
D2: U2.12 (D2), U3.15 (D2), U4.15 (D2); also elsewhere on the board
D3: U2.8 (D3), U3.17 (D3), U4.17 (D3); also elsewhere on the board
D4: U2.7 (D4), U3.18 (D4), U4.18 (D4); also elsewhere on the board
D5: U2.9 (D5), U3.19 (D5), U4.19 (D5); also elsewhere on the board
D6: U2.10 (D6), U3.20 (D6), U4.20 (D6); also elsewhere on the board
D7: U2.13 (D7), U3.21 (D7), U4.21 (D7); also elsewhere on the board
GND: C4.1, C8.1, C45.2, C48.1, C57.2, C58.2, IC6.7 (GND), IC33.7 (GND), S1.1, U2.29 (GND), U3.16 (GND), U3.22 (/CE), U4.16 (GND); also elsewhere on the board
J1OUT: IC33.1; also elsewhere on the board
J2OUT: IC33.3; also elsewhere on the board
unnamed: C45.1, D2.2 (A), R6.2, R9.2, R20.2
unnamed: IC6.1 (~R), IC6.10 (~S), R11.1
unnamed: IC6.4 (~S), IC6.9 (Q)
unnamed: IC33.9, IC33.10
unnamed: IC33.11, R9.1
unnamed: IC33.5, IC33.12
unnamed: R20.1, S1.2
RAMA0: U3.29 (A14), U4.3 (A14); also elsewhere on the board
RAMA1: U3.3 (A15), U4.31 (A15); also elsewhere on the board
RAMA2: U3.2 (A16), U4.2 (A16); also elsewhere on the board
RAMA3: U3.30 (A17), U4.30 (A17); also elsewhere on the board
RAMA4: U3.1 (A18), U4.1 (A18); also elsewhere on the board

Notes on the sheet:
EPM7128S - PLCC-84 / TQPF-100 RAMA0=MA14 : 32K RAMA1=MA15 : 64K RAMA2=MA16 : 128K RAMA3=MA17 : 256K RAMA4=MA18 : 512K = AS6C4008 DIP-32/SOIC-32

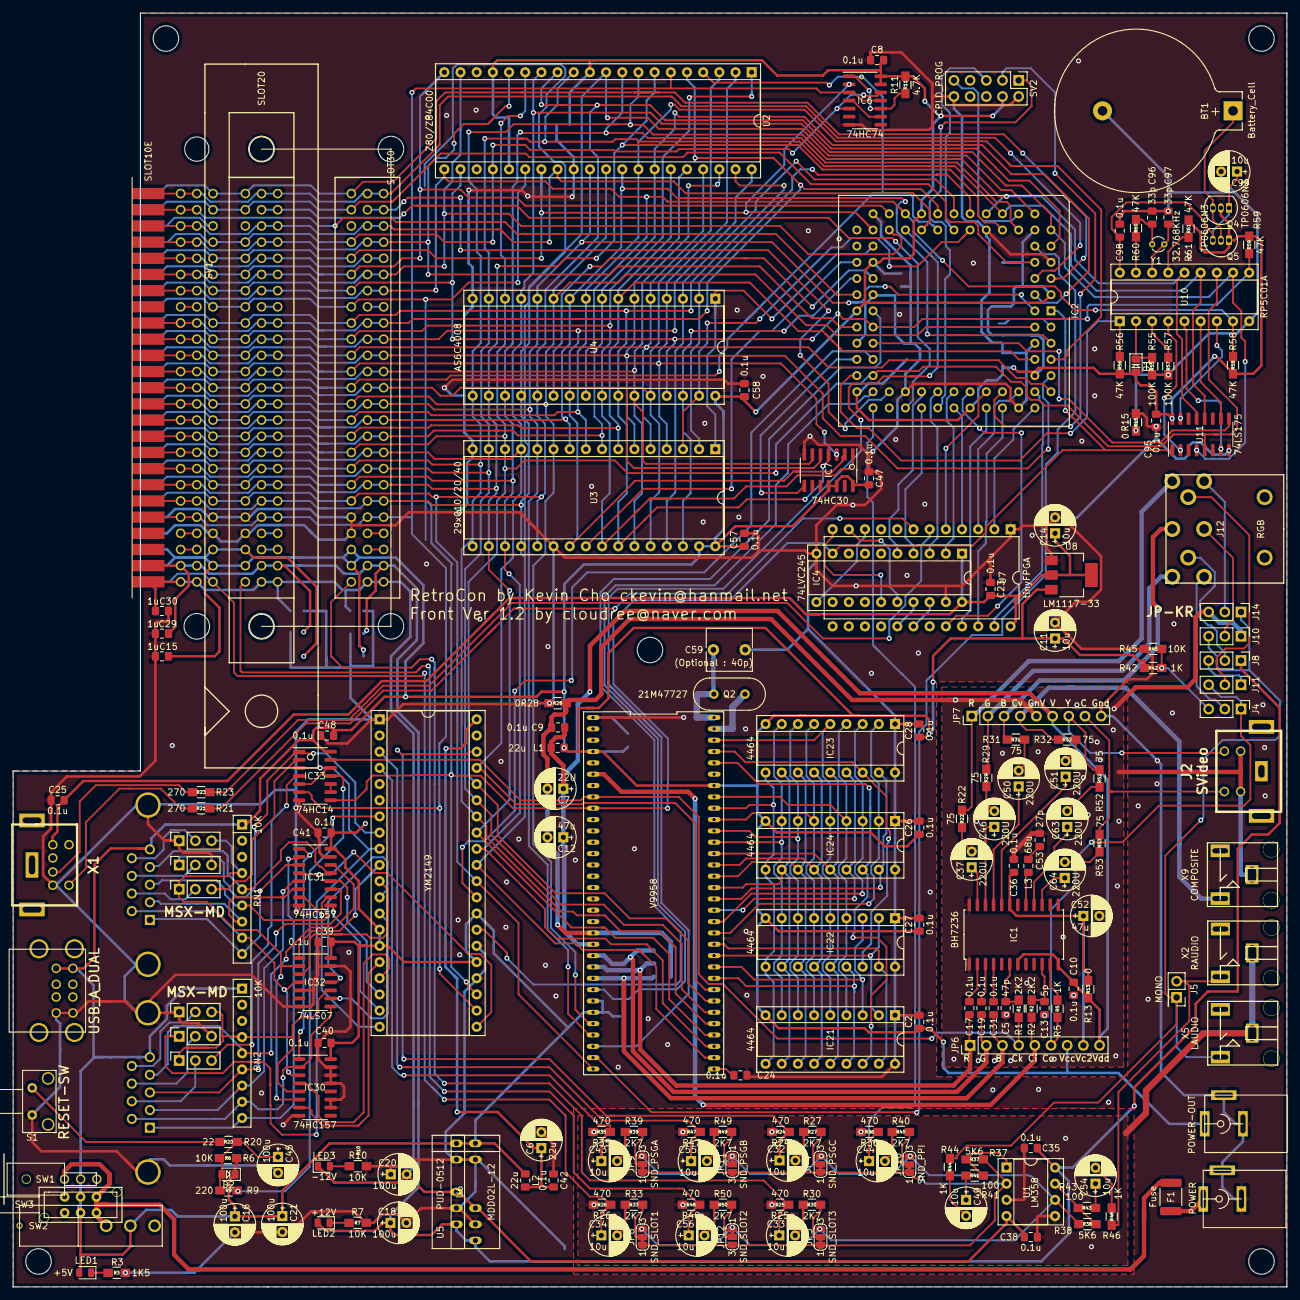
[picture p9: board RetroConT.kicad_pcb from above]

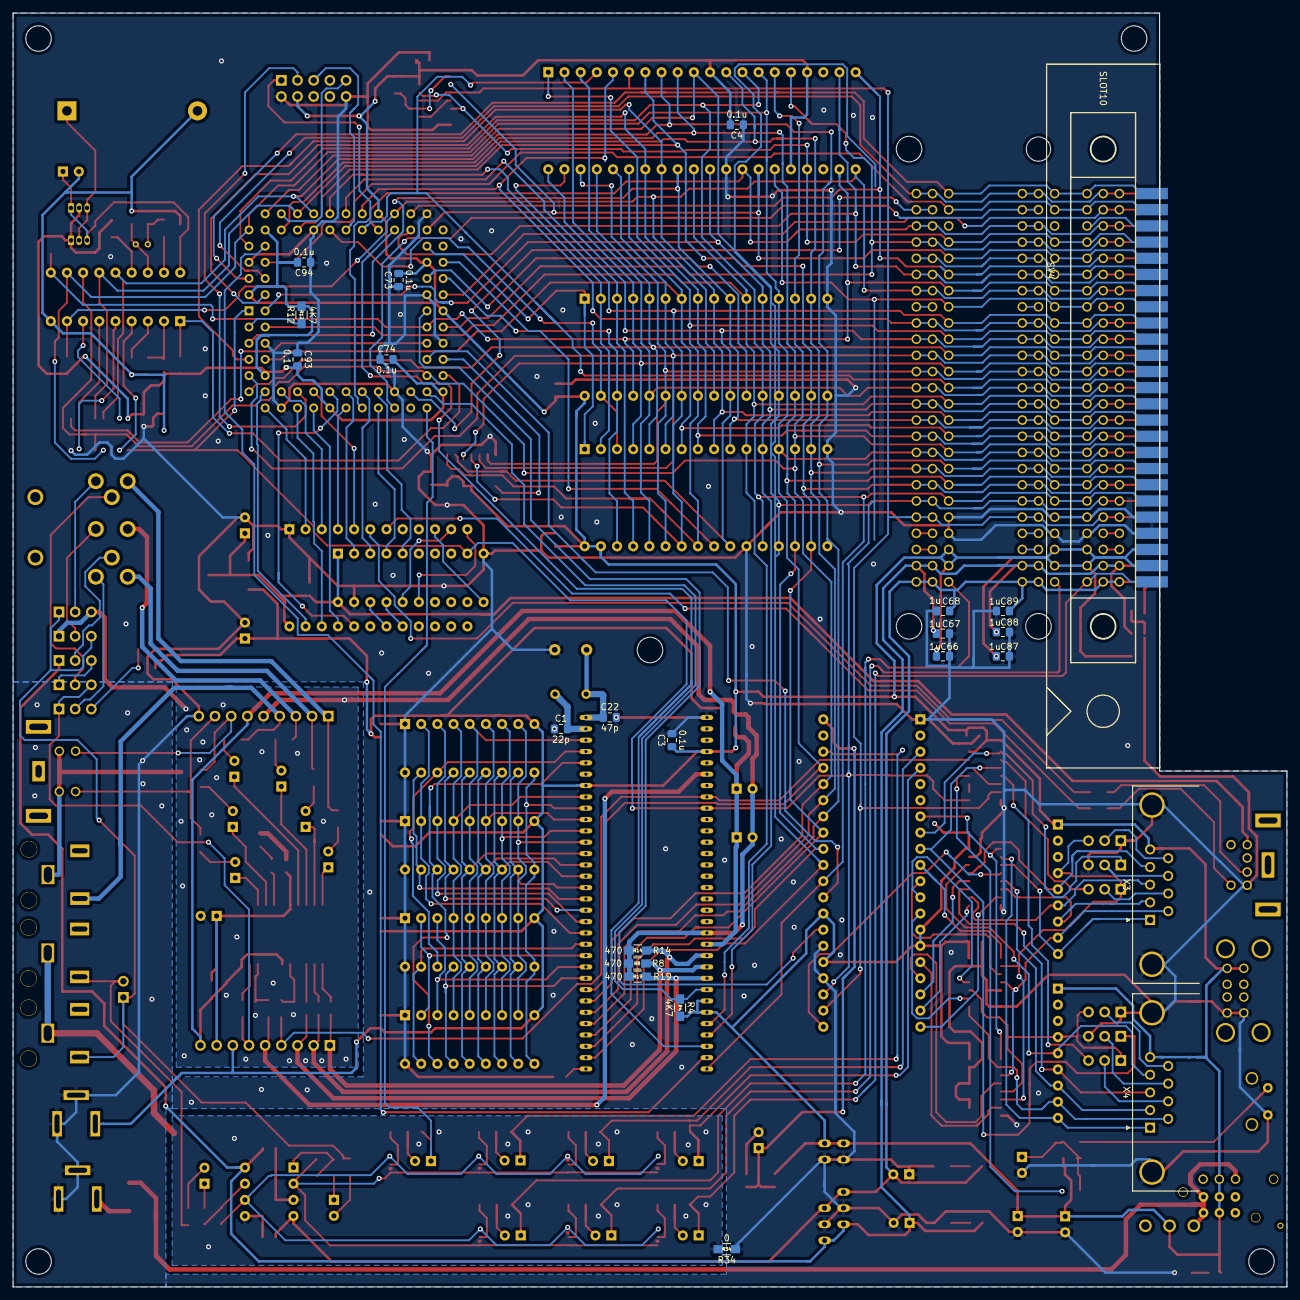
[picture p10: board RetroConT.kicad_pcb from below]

Board: 2 copper layers, 200.0 x 200.0 mm, 214 parts (23 on the bottom side), 245 nets.

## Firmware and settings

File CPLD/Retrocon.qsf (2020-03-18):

# -------------------------------------------------------------------------- #
#
# Copyright (C) 1991-2013 Altera Corporation
# Your use of Altera Corporation's design tools, logic functions 
# and other software and tools, and its AMPP partner logic 
# functions, and any output files from any of the foregoing 
# (including device programming or simulation files), and any 
# associated documentation or information are expressly subject 
# to the terms and conditions of the Altera Program License 
# Subscription Agreement, Altera MegaCore Function License 
# Agreement, or other applicable license agreement, including, 
# without limitation, that your use is for the sole purpose of 
# programming logic devices manufactured by Altera and sold by 
# Altera or its authorized distributors.  Please refer to the 
# applicable agreement for further details.
#
# -------------------------------------------------------------------------- #
#
# Quartus II 64-Bit
# Version 13.0.1 Build 232 06/12/2013 Service Pack 1 SJ Web Edition
# Date created = 04:59:41  October 24, 2019
#
# -------------------------------------------------------------------------- #
#
# Notes:
#
# 1) The default values for assignments are stored in the file:
#		Retrocon_assignment_defaults.qdf
#    If this file doesn't exist, see file:
#		assignment_defaults.qdf
#
# 2) Altera recommends that you do not modify this file. This
#    file is updated automatically by the Quartus II software
#    and any changes you make may be lost or overwritten.
#
# -------------------------------------------------------------------------- #


set_global_assignment -name FAMILY MAX7000S
set_global_assignment -name DEVICE "EPM7128SLC84-10"
set_global_assignment -name TOP_LEVEL_ENTITY Retrocon
set_global_assignment -name ORIGINAL_QUARTUS_VERSION "13.0 SP1"
set_global_assignment -name PROJECT_CREATION_TIME_DATE "04:59:41  OCTOBER 24, 2019"
set_global_assignment -name LAST_QUARTUS_VERSION "13.0 SP1"
set_global_assignment -name MAX7000_DEVICE_IO_STANDARD TTL
set_global_assignment -name OPTIMIZE_HOLD_TIMING OFF
set_global_assignment -name OPTIMIZE_MULTI_CORNER_TIMING OFF
set_global_assignment -name FITTER_EFFORT "STANDARD FIT"
set_global_assignment -name USE_CONFIGURATION_DEVICE ON
set_global_assignment -name ECO_REGENERATE_REPORT ON
set_global_assignment -name OPTIMIZE_IOC_REGISTER_PLACEMENT_FOR_TIMING "PACK ALL IO REGISTERS"
set_global_assignment -name SLOW_SLEW_RATE OFF
set_global_assignment -name AUTO_TURBO_BIT AUTO
set_location_assignment PIN_67 -to PB[7]
set_location_assignment PIN_68 -to PB[6]
set_location_assignment PIN_70 -to PB[5]
set_location_assignment PIN_76 -to PB[4]
set_location_assignment PIN_69 -to PB[3]
set_location_assignment PIN_64 -to PB[2]
set_location_assignment PIN_73 -to PB[1]
set_location_assignment PIN_74 -to PB[0]
set_location_assignment PIN_56 -to CAPS
set_location_assignment PIN_48 -to CK_RTCAL
set_location_assignment PIN_45 -to CPU_INTb
set_location_assignment PIN_30 -to IORQb
set_location_assignment PIN_34 -to M1b
set_location_assignment PIN_31 -to MREQb
set_location_assignment PIN_9 -to data[7]
set_location_assignment PIN_12 -to data[6]
set_location_assignment PIN_15 -to data[5]
set_location_assignment PIN_17 -to data[4]
set_location_assignment PIN_18 -to data[3]
set_location_assignment PIN_16 -to data[2]
set_location_assignment PIN_52 -to data[1]
set_location_assignment PIN_11 -to data[0]
set_location_assignment PIN_61 -to keyMAT[3]
set_location_assignment PIN_60 -to keyMAT[2]
set_location_assignment PIN_63 -to keyMAT[1]
set_location_assignment PIN_65 -to keyMAT[0]
set_location_assignment PIN_24 -to addrH[15]
set_location_assignment PIN_25 -to addrH[14]
set_location_assignment PIN_75 -to addrL[7]
set_location_assignment PIN_77 -to addrL[6]
set_location_assignment PIN_80 -to addrL[5]
set_location_assignment PIN_4 -to addrL[4]
set_location_assignment PIN_79 -to addrL[3]
set_location_assignment PIN_81 -to addrL[2]
set_location_assignment PIN_84 -to addrL[1]
set_location_assignment PIN_2 -to addrL[0]
set_location_assignment PIN_21 -to RAMA[1]
set_location_assignment PIN_22 -to RAMA[0]
set_location_assignment PIN_51 -to RTCCSb
set_location_assignment PIN_46 -to WRb
set_location_assignment PIN_49 -to addr13_8b
set_location_assignment PIN_28 -to RDb
set_location_assignment PIN_37 -to ROM_OEb
set_location_assignment PIN_1 -to RSTb
set_location_assignment PIN_83 -to SLT_INTb
set_location_assignment PIN_58 -to SLTbo[2]
set_location_assignment PIN_41 -to SLTbo[1]
set_location_assignment PIN_54 -to SPK
set_location_assignment PIN_5 -to PG1RDb
set_location_assignment PIN_6 -to PG2RDb
set_location_assignment PIN_8 -to PG12RDb
set_location_assignment PIN_50 -to PSGBC1
set_location_assignment PIN_44 -to PSGBDIR
set_location_assignment PIN_27 -to RFSHb
set_location_assignment PIN_10 -to VDP_CSRb
set_location_assignment PIN_29 -to VDP_CSWb
set_location_assignment PIN_55 -to VDP_INTb
set_location_assignment PIN_20 -to RAMA[2]
set_location_assignment PIN_40 -to RAM_CSb
set_location_assignment PIN_39 -to RAMA[3]
set_location_assignment PIN_57 -to RAMA[4]
set_global_assignment -name VERILOG_FILE ramMapper.v
set_global_assignment -name VERILOG_FILE PPI8255.v
set_global_assignment -name VERILOG_FILE slotExp.v
set_global_assignment -name VERILOG_FILE Retrocon.v
set_global_assignment -name VERILOG_FILE PPI8255_SLT.v
set_global_assignment -name CDF_FILE Retrocon.cdf

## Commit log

2020-04-04 Fix up some bugs
    fix up around XTAL and add variable capacitor.
    fix the position of Joystick ports.
    fix +5V supply around DC2DC.
    [RetroConT-B_Cu.gbr, RetroConT-B_Mask.gbr, RetroConT-B_SilkS.gbr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]
2020-04-04 fix up some details
    change proper value of Capacitor for XTAL
    [RetroConT-B_Cu.gbr, RetroConT-B_Mask.gbr, RetroConT-B_SilkS.gbr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]
